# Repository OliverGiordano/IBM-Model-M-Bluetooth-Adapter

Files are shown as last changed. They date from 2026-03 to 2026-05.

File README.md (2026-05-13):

# IBM Model M Bluetooth Adapter

A Bluetooth adapter for the IBM Model M PS/2 keyboard. The adapter converts PS/2 signals from the keyboard to HID signals that are sent over Bluetooth to a computer.

<div align="center">

</div>

---

## Project Goals

When I started this project I wanted to create a wireless way for my IBM Model M keyboard to connect to my Apple computer. When I use the adapter I bought off Amazon, my MacBook thought my keyboard was a barcode reader, which was not ideal.

---

## Project Iterations

### Iteration 1 — Custom Controller Replacement

My first attempt was to replace the control board on my keyboard entirely with a custom solution. The main advantage of this method was power efficiency — the giant microcontroller in the Model M is very old and eats energy. When plugged into a desktop this doesn't cause a problem, but on a limited battery it could be an issue.

<div align="center">

</div>

After some initial testing I chose to scrap this idea for a few reasons:

- I needed to disassemble the keyboard every time I wanted to work on the adapter, then reassemble it every time I wanted to use it.
- The membrane requires 26 GPIO ports to interface with the matrix. This was doable with an I2C GPIO extender, but it made the breadboarded prototype very difficult to debug since each connection was a new point of failure.
- It required using terrible membrane connectors.

<div align="center">

</div>

---

### Iteration 2 — PS/2 Adapter

My second iteration was creating an adapter that plugs into the Model M's PS/2 output. This was very convenient because I could cut one head off an existing adapter and directly break out the wiring. This solution is easy to wire and test because the PS/2 standard only has 4 wires: Data, Clock, 5V, and GND.

<div align="center">


</div>

For this project I chose to use the **Adafruit Feather ESP32**. I chose this microcontroller because it has built-in Bluetooth and a built-in battery circuit, and it was only around $8 — great for my budget.

One problem I didn't realize when picking it was that the Model M and the PS/2 standard require 5V input, but the Feather only supplies 3.3V. Because of this, I currently pull power for the PS/2 directly from the 5V USB line, which means the adapter needs to be plugged into a power source for now since the battery cannot supply 5V. In the future I plan to add a voltage booster for the 3.3V line, but it hasn't arrived yet.

Since reading 5V on the Feather would destroy the microcontroller, I use **voltage dividers** on the Data and Clock lines. Each divider consists of 3 resistors of equal resistance, with two wired in series.

<div align="center">


</div>

---

## Updates

Fixing the issue of the Feather not being able to supply 5V for the keyboard, I updated my design to include a voltage booster. The voltage booster I choose to use was the MT3608, a voltage booster that could vary output with a variable resistor.  I connected it to a PSU and set the PSU to 3.3V, then used a multimeter to mesure the voltage as I adjusted the resistor.



When attaching the voltage booster I re-wired the rest of the board to be more durrable and fit into a smaller space, here was my final build front and back:




I also have been working on making a single PCB for the design to continue improving its durability and decreasing size unfortunatly it is a little out of my budget and I don't have the tools I will need to assemble it so that portion will be tabled for now.

here are my schematics and layouts:




---

## Software

The code uses 3 libraries:

- **PS2KeyAdvanced** — reads the serial output from the keyboard
- **PS2KeyMap** — maps PS2KeyAdvanced output to proper HID commands
- **BleKeyboard** — sends HID commands via Bluetooth

PS2KeyMap works for about 90% of keys. For the remaining 10%, I manually printed the output from PS2KeyAdvanced key by key and mapped them through a switch statement.

The code also reports battery level. The Adafruit Feather maps the battery voltage through an internal divider to analog pin 13 (GPIO 35), so to read the voltage I read GPIO 35 and multiply by two.

---

## Known Issues

The lock keys (Caps Lock, Scroll Lock, Num Lock) do not light up their respective LEDs. At first, pressing these keys froze the keyboard entirely. To fix this, I went into the PS2KeyAdvanced library and remapped the lock keys to keys not present on my keyboard, then handled them manually in code.

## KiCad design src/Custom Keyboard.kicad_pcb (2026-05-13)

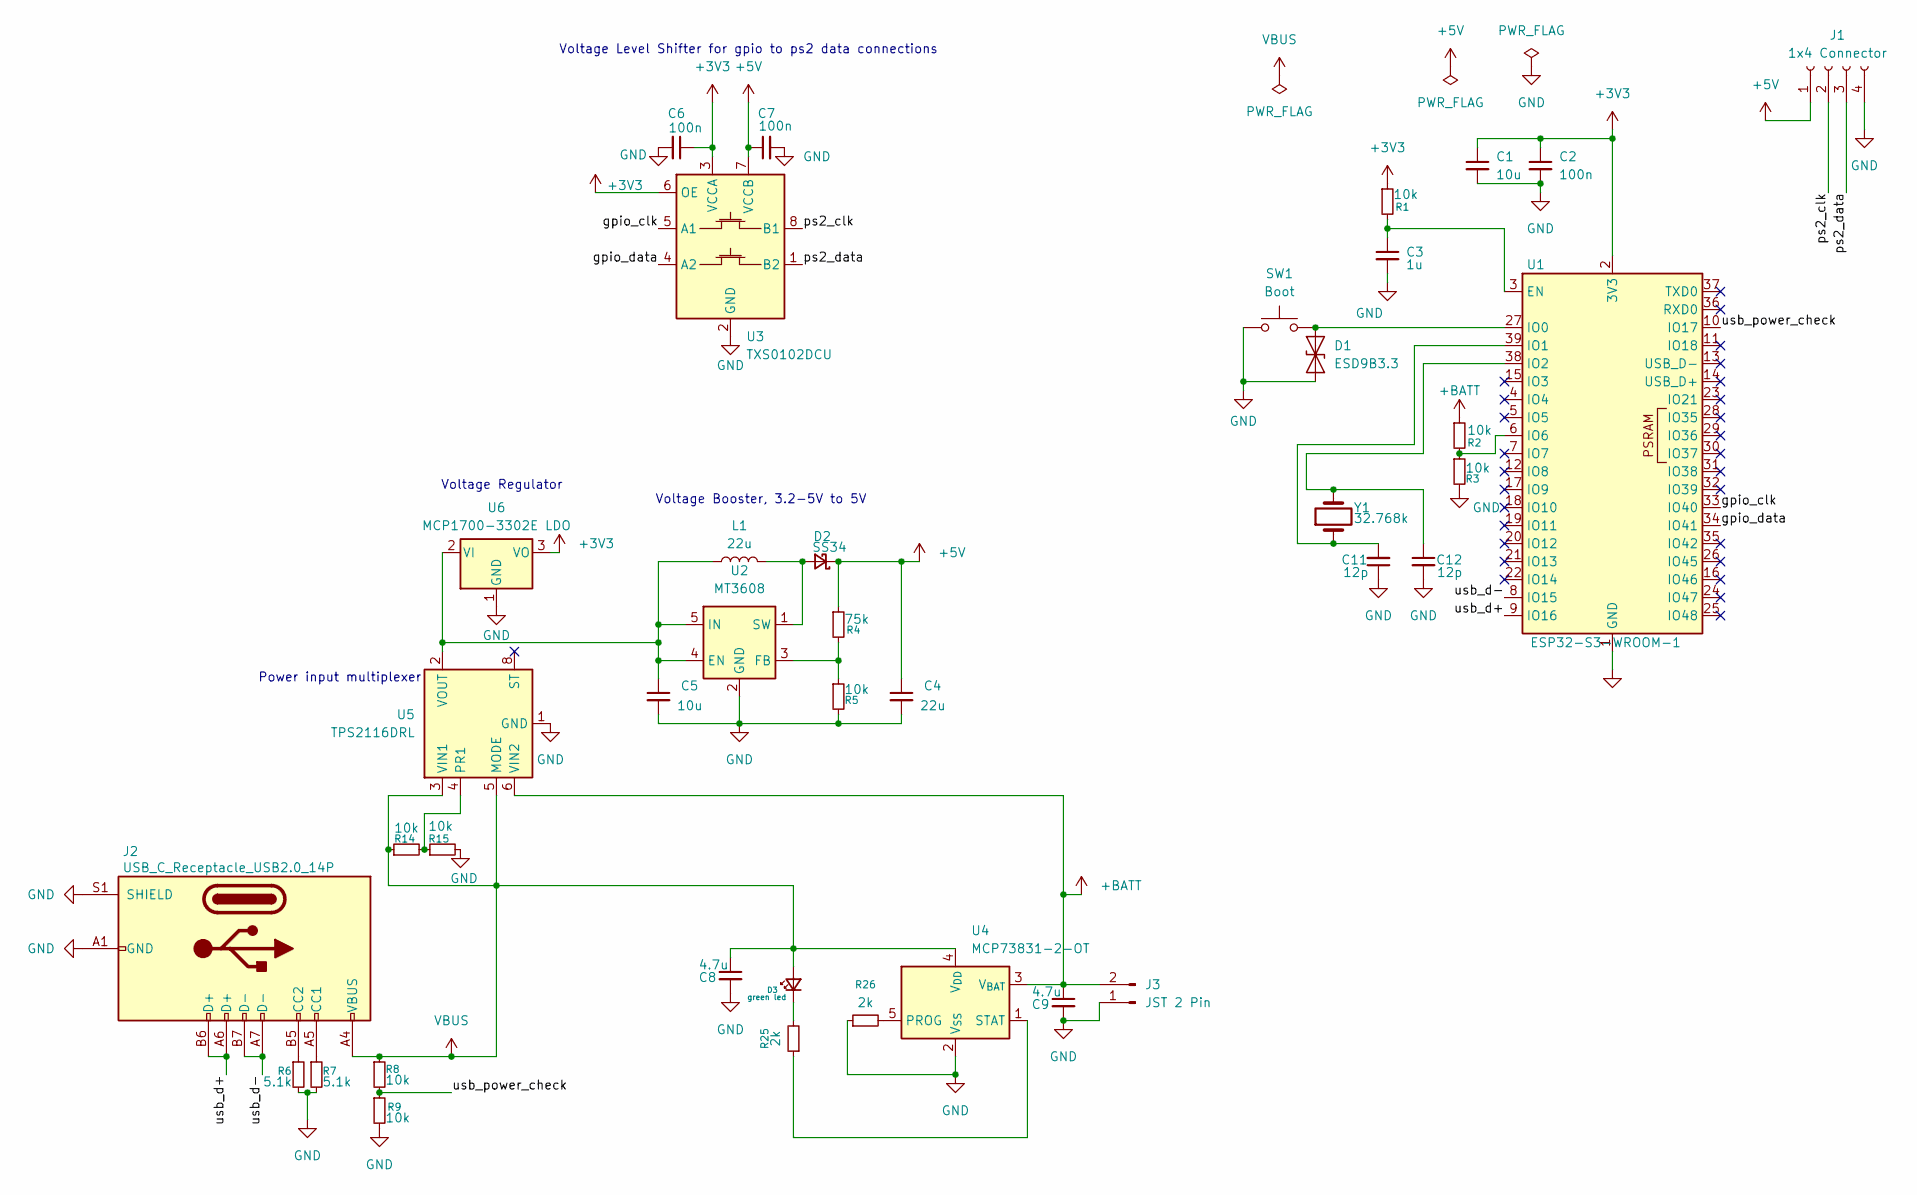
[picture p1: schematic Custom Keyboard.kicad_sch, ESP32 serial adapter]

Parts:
C1, C5: 10u; C_0402_1005Metric_Pad0.74x0.62mm_HandSolder
C2, C6, C7: 100n; C_0402_1005Metric_Pad0.74x0.62mm_HandSolder
C3: 1u; C_0402_1005Metric_Pad0.74x0.62mm_HandSolder
C4: 22u; C_0402_1005Metric_Pad0.74x0.62mm_HandSolder
C8, C9: 4.7u; C_0402_1005Metric_Pad0.74x0.62mm_HandSolder
C11, C12: 12p; C_0402_1005Metric_Pad0.74x0.62mm_HandSolder
D1: ESD9B3.3; D_SOD-923
D2: SS34; D_SOD-123F
D3: green led; LED_0402_1005Metric
J1: 1x4 Connector; PinHeader_1x04_P1.27mm_Vertical
J2: USB_C_Receptacle_USB2.0_14P; USB_C_Receptacle_HRO_TYPE-C-31-M-12
J3: JST 2 Pin; JST_ACH_BM02B-ACHSS-GAN-ETF_1x02-1MP_P1.20mm_Vertical
L1: 22u; L_Bourns_SRR1260
R1, R2, R3, R5, R8, R9, R14, R15: 10k; R_0402_1005Metric_Pad0.72x0.64mm_HandSolder
R4: 75k; R_0402_1005Metric_Pad0.72x0.64mm_HandSolder
R6, R7: 5.1k; R_0402_1005Metric_Pad0.72x0.64mm_HandSolder
R25, R26: 2k; R_0402_1005Metric_Pad0.72x0.64mm_HandSolder
SW1: Boot; SW_SPST_Omron_B3FS-100xP
U1: ESP32-S3-WROOM-1
U2: MT3608; SOT-23-6
U3: TXS0102DCU; VSSOP-8_2.3x2mm_P0.5mm
U4: MCP73831-2-OT; SOT-23-5
U5: TPS2116DRL; SOT-583-8
U6: MCP1700-3302E LDO; SOT-89-3
Y1: 32.768k; Crystal_SMD_3215-2Pin_3.2x1.5mm

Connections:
+3V3: C1.1, C2.1, C6.1, R1.1, U1.2 (3V3), U3.3 (VCCA), U3.6 (OE), U6.3 (VO)
+5V: C4.1, C7.1, D2.1 (K), J1.1, R4.1, U3.7 (VCCB)
+BATT: C9.1, J3.2, R2.1, U4.3 (V_{BAT}), U5.6 (VIN2)
/gpio_clk: U1.33 (IO40), U3.5 (A1)
/gpio_data: U1.34 (IO41), U3.4 (A2)
/ps2_clk: J1.2, U3.8 (B1)
/ps2_data: J1.3, U3.1 (B2)
/usb_d+: J2.A6 (D+), J2.B6 (D+), U1.9 (IO16)
/usb_d-: J2.A7 (D-), J2.B7 (D-), U1.8 (IO15)
/usb_power_check: R8.2, R9.1, U1.10 (IO17)
GND: C1.2, C2.2, C3.2, C4.2, C5.2, C6.2, C7.2, C8.2, C9.2, C11.1, C12.2, D1.1 (A1), J1.4, J2.A1 (GND), J2.A12 (GND), J2.B1 (GND), J2.B12 (GND), J2.S1 (SHIELD), J3.1, R3.2, R5.2, R6.2, R7.2, R9.2, R15.2, R26.1, SW1.1, U1.1 (GND), U1.40 (GND), U1.41 (GND), U2.2 (GND), U3.2 (GND), U4.2 (V_{SS}), U5.1 (GND), U6.1 (GND)
unnamed: D1.2 (A2), SW1.2, U1.27 (IO0)
unnamed: D2.2 (A), L1.2, U2.1 (SW)
unnamed: D3.1 (K), R25.2
unnamed: J2.A5 (CC1), R7.1
unnamed: J2.B5 (CC2), R6.1
unnamed: C3.1, R1.2, U1.3 (EN)
unnamed: C11.2, U1.39 (IO1), Y1.1
unnamed: C12.1, U1.38 (IO2), Y1.2
unnamed: R2.2, R3.1, U1.6 (IO6)
unnamed: C5.1, L1.1, U2.4 (EN), U2.5 (IN), U5.2 (VOUT), U5.7 (VOUT), U6.2 (VI)
unnamed: R4.2, R5.1, U2.3 (FB)
unnamed: R26.2, U4.5 (PROG)
unnamed: R25.1, U4.1 (STAT)
unnamed: R14.2, R15.1, U5.4 (PR1)
VBUS: C8.1, D3.2 (A), J2.A4 (VBUS), J2.A9 (VBUS), J2.B4 (VBUS), J2.B9 (VBUS), R8.1, R14.1, U4.4 (V_{DD}), U5.3 (VIN1), U5.5 (MODE)

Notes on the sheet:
Voltage Booster, 3.2-5V to 5V
Power input multiplexer
Voltage Level Shifter for gpio to ps2 data connections
Voltage Regulator

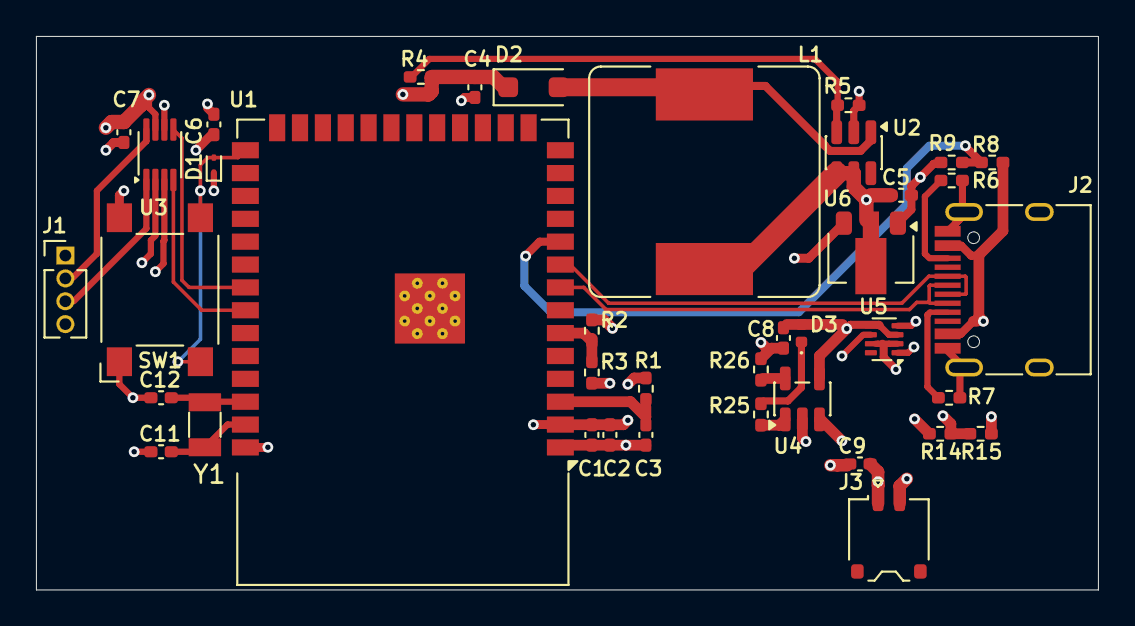
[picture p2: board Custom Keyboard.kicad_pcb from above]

Board: 4 copper layers, 59.0 x 30.8 mm, 39 parts (0 on the bottom side), 26 nets.

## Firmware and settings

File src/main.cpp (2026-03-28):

#include <Arduino.h>
#include <PS2KeyAdvanced.h>
#include <PS2KeyMap.h>
#include <BleKeyboard.h>

// GPIO pins
#define PS2_DATA 32
#define PS2_CLK 13
#define BATTERY_IO 35

// extra keybind mappings
#define PS2_CAPSLOCK 0x98
#define PS2_SCROLLLOCK 0x96

// battery percentage scheduling scheduling
#define BATTERY_MONITOR_INTERVEL 10 // Seconds
unsigned long previousMillis = 0;

PS2KeyAdvanced keyboard;
PS2KeyMap keymap;
BleKeyboard bleKeyboard("Model M", "IBM", 100);


// Returns voltage of battery in volts
float readVoltage() {
  int raw = analogRead(BATTERY_IO);
  float voltage = (raw / 4095.0) * 2 * 3.3 * 1.1; // gotta multiply by 2 because of the
                                                  // built in voltage divider on A13
  return voltage;
}

// Returns percentage of battery
float readBatteryPercent() {
  float voltage = readVoltage();
  if (4.2 <= voltage) return 100;
  if (3.2 >= voltage) return 0;
  return (voltage - 3.2)*100;
}

void setup() {
  Serial.begin(115200);
  bleKeyboard.begin();
  delay(500); // half second delay between BLE initialization and keyboard initiallzation
  keyboard.begin(PS2_DATA, PS2_CLK);
  keymap.selectMap((char*)"US");
}

void loop() {
  //Serial.printf("Battery Percent %f\n", readBatteryPercent(readVoltage()));
  unsigned long currentMillis = millis();
  if (BATTERY_MONITOR_INTERVEL*1000 <= currentMillis-previousMillis) {
    previousMillis = currentMillis;
    bleKeyboard.setBatteryLevel(readBatteryPercent());
  }
  if (keyboard.available()) {
    uint16_t raw = keyboard.read();
    uint16_t key = keymap.remapKey(raw);
    Serial.printf("raw: 0x%04X key: 0x%04X code: 0x%02X\n", raw, key, key & 0xFF);
    uint8_t rawCode = raw & 0xFF;
    if (!(raw & PS2_BREAK)) {
      switch (rawCode) {
        case PS2_KEY_UP_ARROW: bleKeyboard.write(KEY_UP_ARROW); break;
        case PS2_KEY_DN_ARROW: bleKeyboard.write(KEY_DOWN_ARROW); break;
        case PS2_KEY_L_ARROW:  bleKeyboard.write(KEY_LEFT_ARROW); break;
        case PS2_KEY_R_ARROW:  bleKeyboard.write(KEY_RIGHT_ARROW); break;
        case PS2_KEY_L_CTRL:   bleKeyboard.press(KEY_LEFT_CTRL); break;
        case PS2_KEY_R_CTRL:   bleKeyboard.press(KEY_RIGHT_CTRL); break;
        case PS2_KEY_L_ALT:    bleKeyboard.press(KEY_LEFT_GUI); break;
        case PS2_KEY_R_ALT:    bleKeyboard.press(KEY_RIGHT_GUI); break;
        case PS2_CAPSLOCK:     bleKeyboard.press(KEY_CAPS_LOCK); break;
        case PS2_SCROLLLOCK:   bleKeyboard.press(KEY_LEFT_ALT); break; // I am maping scroll lock to option
      }
    } else {
      // Release modifiers on key up
      switch (rawCode) {
        case PS2_KEY_L_CTRL:   bleKeyboard.release(KEY_LEFT_CTRL); break;
        case PS2_KEY_R_CTRL:   bleKeyboard.release(KEY_RIGHT_CTRL); break;
        case PS2_KEY_L_ALT:    bleKeyboard.release(KEY_LEFT_GUI); break;
        case PS2_KEY_R_ALT:    bleKeyboard.release(KEY_RIGHT_GUI); break;
        case PS2_CAPSLOCK:     bleKeyboard.release(KEY_CAPS_LOCK); break;
        case PS2_SCROLLLOCK:   bleKeyboard.release(KEY_LEFT_ALT); break; // I am maping scroll lock to option
      }
    }
    if (key > 0 && !(key & PS2_BREAK)) {
      uint8_t code = key & 0xFF;
      Serial.println(code);
      // Special keys
      if (code == 8)   { bleKeyboard.write(KEY_BACKSPACE); return; }
      if (code == 13)  { bleKeyboard.write(KEY_RETURN); return; }
      if (code == 9)   { bleKeyboard.write(KEY_TAB); return; }
      if (code == 27)  { bleKeyboard.write(KEY_ESC); return; }
      if (code == 127) { bleKeyboard.write(KEY_DELETE); return; }
      
      // Regular characters
      if (code >= 32 && code < 128) {
        if (bleKeyboard.isConnected()) {
          bleKeyboard.write(code);
        }
      }
    }
  }
}

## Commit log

2026-05-13 Document updates on design improvements and voltage booster
    Added section detailing updates to the design, including the integration of a voltage booster and improvements in wiring for durability and size.
2026-05-13 Add custom pcb files
    [Custom Keyboard.kicad_pcb, Custom Keyboard.kicad_sch]
